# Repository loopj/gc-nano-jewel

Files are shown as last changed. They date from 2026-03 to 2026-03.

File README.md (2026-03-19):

# GC Nano LCD Jewel

Custom LCD "jewel" insert for the [GC Nano](https://bitbuilt.net/forums/threads/gc-nano-the-worlds-smallest-gamecube.5697/), using an ESP32-C3 and a lensed 0.96" round LCD.

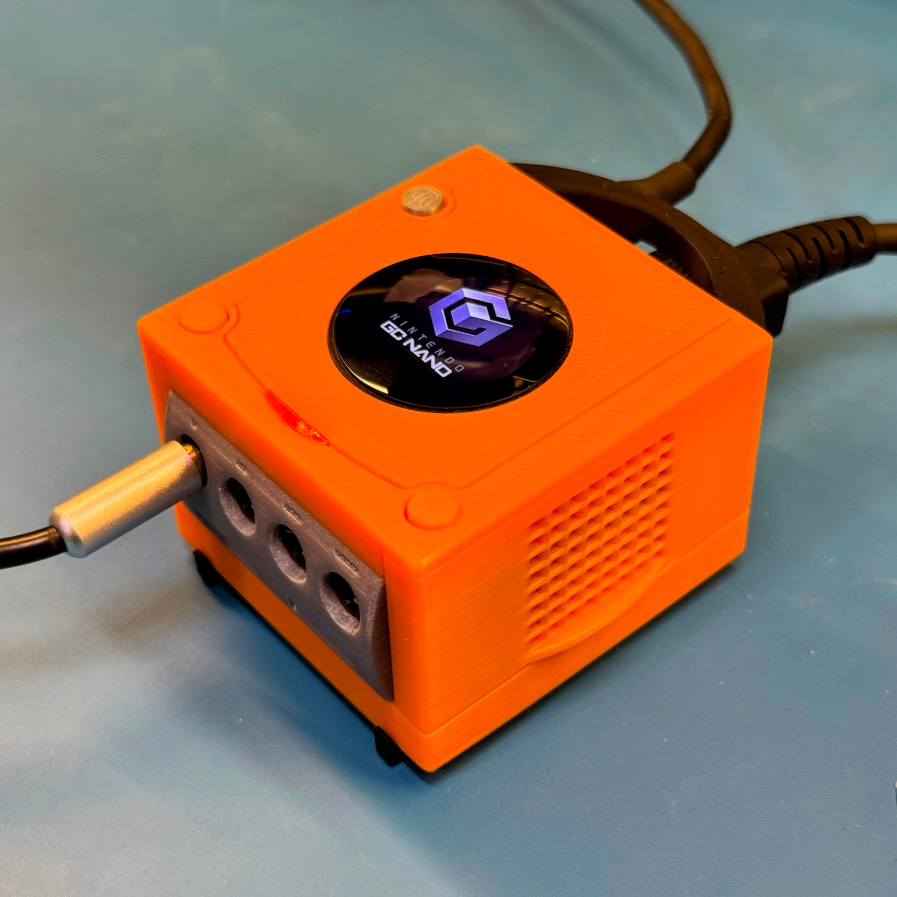
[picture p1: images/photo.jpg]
GC Nano LCD Jewel animation demo


## Features

- Fits in an unmodified GC Nano shell
- Displays a static or animated GIF (240x198, < 1,408 KB)
- WiFi access point and web interface for uploading new GIFs
- OTA firmware updates so you don't have to open the case again

## Bill of Materials

- ESP32-C3 Super Mini (or similar) - [AliExpress](https://www.aliexpress.us/item/3256808827955225.html)
- 0.96" 240x198 Round LCD - [AliExpress](https://www.aliexpress.us/item/3256806072157291.html), [docs](https://www.lcdwiki.com/0.96inch_IPS_ST7789_Module)
- Some wire
- 3D printed insert (see [`hardware/` folder](hardware/))

## Assembly

The LCD should be wired to the following pins on the ESP32-C3:

| LCD Pin | ESP32-C3 Pin | Function |
|---|---|---|
| GND | GND | Ground |
| VCC | 3.3V | Power |
| SCL | GPIO4 | SPI Clock |
| SDA | GPIO6 | SPI MOSI |
| CS | GPIO7 | SPI Chip Select  |
| DC | GPIO2 | Data/Command |
| RST | GPIO1 | Reset |

You'll also need to connect GND and 5V on the ESP32-C3 to the corresponding pads on the GC Nano top board.

The screen should press-fit from the top into the 3D printed insert, which can then be glued into the GC Nano shell. The ESP32-C3 can be mounted on the back of the insert with some double-sided tape.

Flash the firmware before closing everything up.

## Flashing the Firmware

### Using a Browser-Based Flasher

- Plug in the ESP32-C3 to your computer via USB
- Go to <https://www.espboards.dev/tools/program/> and click *Connect to ESP*
- Click *Flash firmware*
- Set the *Flash Address* to `0x0` an click *Choose File*
- Select the `factory.bin` file you downloaded from the [releases](https://github.com/loopj/gc-nano-jewel/releases) page
- Click *Program* and wait for it to finish

### Using PlatformIO

- Install PlatformIO
- Plug in the ESP32-C3 to your computer via USB
- Run `pio run -t upload` from the `firmware` directory

## Usage

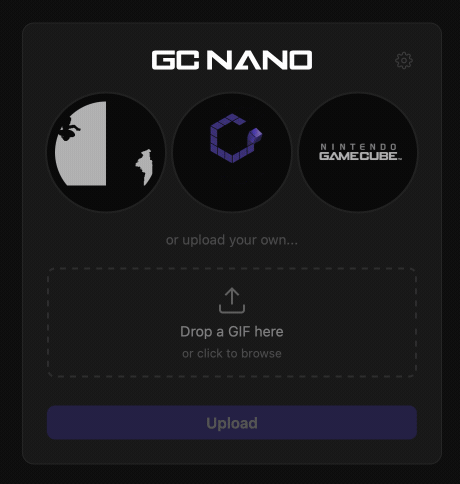
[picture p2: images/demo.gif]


### Uploading GIFs

- Connect to the "GCNANO-XXXXXX" WiFi network (password: "bitbuilt")
- Open a web browser and navigate to <http://gcnano.local>
- Upload the GIF!

### Settings

Clicking the cog icon in the top right of the page will flip to the settings page. By default, the settings page is locked. To unlock it, enter the settings password (default: "bitbuilt") and click "Unlock".

### Connecting to WiFi

By default, the firmware creates its own WiFi AP. You can instead connect to your home WiFi network by entering the SSID and password in the settings page.

### Pre-made GIFs

There are a couple of pre-made GIFs in the [`gifs/` folder](gifs/). If you want to make your own, make sure to resize it to 240x198 and keep the file size under 1,408 KB. Please send me your GIFs and I'll add them to the collection!

<table>
  <tr>
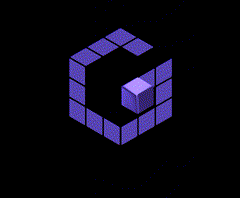
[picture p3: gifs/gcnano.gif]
    <td></td>
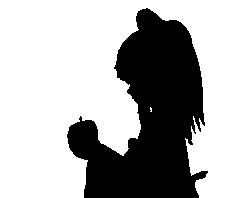
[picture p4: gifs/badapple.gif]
    <td></td>
  </tr>
</table>

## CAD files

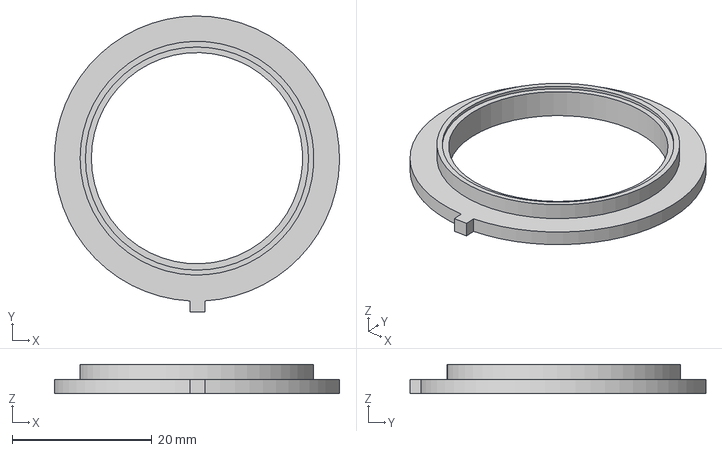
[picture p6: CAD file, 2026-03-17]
hardware/GC Nano LCD Jewel.step
40.8 x 42.3 x 4.20 mm

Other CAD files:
hardware/GC Nano LCD Jewel.stl

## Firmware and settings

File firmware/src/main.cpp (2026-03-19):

#include <AnimatedGIF.h>
#include <Arduino.h>
#include <ESPmDNS.h>
#include <LittleFS.h>
#include <Preferences.h>
#include <TFT_eSPI.h>
#include <Update.h>
#include <WebServer.h>
#include <WiFi.h>

#include "AnimatedGIF_LittleFS.h"
#include "AnimatedGIF_TFT_eSPI.h"

// Static assets
extern const uint8_t index_html_start[] asm("_binary_assets_index_html_start");
extern const uint8_t index_html_end[] asm("_binary_assets_index_html_end");
extern const uint8_t default_gif_start[] asm("_binary_assets_default_gif_start");
extern const uint8_t default_gif_end[] asm("_binary_assets_default_gif_end");

#define PASSWORD "bitbuilt"

WebServer server(80);
TFT_eSPI tft = TFT_eSPI();
AnimatedGIF gif;
bool gifPaused             = false;
bool gifNeedsReload        = false;
static bool settingsLocked = true;

void handleUnlock()
{
  Preferences prefs;
  prefs.begin("wifi", true);
  String settingsPass = prefs.getString("settingspass", "bitbuilt");
  prefs.end();
  if (server.arg("password") == settingsPass) {
    settingsLocked = false;
    server.send(200, "text/plain", "Unlocked");
  } else {
    server.send(401, "text/plain", "Incorrect password");
  }
}

void handleLock()
{
  settingsLocked = true;
  server.send(200, "text/plain", "Locked");
}

void handleGetLocked()
{
  server.send(200, "application/json", settingsLocked ? "true" : "false");
}

void handleOta()
{
  HTTPUpload &upload = server.upload();
  if (upload.status == UPLOAD_FILE_START) {
    if (settingsLocked)
      return;
    gifPaused = true;
    gif.close();
    size_t fsize = UPDATE_SIZE_UNKNOWN;
    if (server.hasArg("size"))
      fsize = server.arg("size").toInt();
    Update.begin(fsize);
  } else if (upload.status == UPLOAD_FILE_WRITE) {
    if (!settingsLocked)
      Update.write(upload.buf, upload.currentSize);
  } else if (upload.status == UPLOAD_FILE_END) {
    if (!settingsLocked)
      Update.end(true);
  }
}

void handleOtaEnd()
{
  server.sendHeader("Connection", "close");
  if (settingsLocked) {
    server.send(401, "text/plain", "Unauthorized");
    return;
  }
  if (Update.hasError()) {
    gifPaused = false;
    server.send(502, "text/plain", Update.errorString());
    return;
  }
  server.send(200, "text/plain", "Update complete, rebooting...");
  delay(500);
  ESP.restart();
}

void handleImageGet()
{
  if (!LittleFS.exists("/uploaded.gif")) {
    server.send(404, "text/plain", "No image uploaded");
    return;
  }
  File f = LittleFS.open("/uploaded.gif", "r");
  server.streamFile(f, "image/gif");
  f.close();
}

void handleImageDelete()
{
  if (!LittleFS.exists("/uploaded.gif")) {
    server.send(404, "text/plain", "No image uploaded");
    return;
  }
  gif.close();
  LittleFS.remove("/uploaded.gif");
  gifNeedsReload = true;
  server.send(200, "text/plain", "Image deleted");
}

static File uploadFile;

void handleImageUpload()
{
  HTTPUpload &upload = server.upload();

  if (upload.status == UPLOAD_FILE_START) {
    gifPaused = true;
    gif.close();
    uploadFile = LittleFS.open("/uploaded.gif", "w");
  } else if (upload.status == UPLOAD_FILE_WRITE) {
    if (uploadFile) {
      uploadFile.write(upload.buf, upload.currentSize);
    }
  } else if (upload.status == UPLOAD_FILE_END) {
    if (uploadFile) {
      uploadFile.close();
    }
  }
}

void handleImageUploadEnd()
{
  gifNeedsReload = true;
  gifPaused      = false;
  server.sendHeader("Connection", "close");
  server.send(200, "text/plain", "Image uploaded successfully");
}

void handleGetSettings()
{
  if (settingsLocked) {
    server.send(401, "text/plain", "Unauthorized");
    return;
  }

  Preferences prefs;
  prefs.begin("wifi", true);
  String savedSsid = prefs.getString("ssid", "");
  bool hasPassword = prefs.getString("pass", "").length() > 0;
  prefs.end();

  bool isSta     = WiFi.getMode() == WIFI_STA;
  bool connected = isSta && WiFi.status() == WL_CONNECTED;
  String ip      = connected ? WiFi.localIP().toString() : WiFi.softAPIP().toString();

  String json = "{";
  json += "\"ssid\":\"" + savedSsid + "\",";
  json += "\"hasPassword\":" + String(hasPassword ? "true" : "false") + ",";
  json += "\"mode\":\"" + String(isSta ? "sta" : "ap") + "\",";
  json += "\"connected\":" + String(connected ? "true" : "false") + ",";
  json += "\"ip\":\"" + ip + "\"";
  json += "}";
  server.send(200, "application/json", json);
}

void handleSaveSettings()
{
  if (settingsLocked) {
    server.send(401, "text/plain", "Unauthorized");
    return;
  }

  String newSsid         = server.arg("ssid");
  String newPass         = server.arg("pass");
  String newSettingsPass = server.arg("settingspass");

  Preferences prefs;
  prefs.begin("wifi", false);
  prefs.putString("ssid", newSsid);
  if (newPass.length() > 0)
    prefs.putString("pass", newPass);
  if (newSettingsPass.length() > 0)
    prefs.putString("settingspass", newSettingsPass);
  prefs.end();

  server.send(200, "text/plain", "Saved. Rebooting...");
  delay(500);
  ESP.restart();
}

void setup()
{
  // Initialize filesystem
  LittleFS.begin(true);

  // Initialize screen
  tft.init();
  tft.fillScreen(TFT_BLACK);

  // Initialize GIF decoder
  gif.begin(BIG_ENDIAN_PIXELS);

  // Generate a unique SSID based on MAC address (used as AP fallback)
  char apSsid[14];
  long unsigned int espmac = ESP.getEfuseMac() >> 24;
  snprintf(apSsid, sizeof(apSsid), "GCNANO-%06lX", espmac);

  // Try to connect to a saved WiFi network, otherwise start AP
  Preferences prefs;
  prefs.begin("wifi", true);
  String savedSsid = prefs.getString("ssid", "");
  String savedPass = prefs.getString("pass", "");
  prefs.end();

  if (savedSsid.length() > 0) {
    WiFi.mode(WIFI_STA);
    WiFi.begin(savedSsid.c_str(), savedPass.c_str());
    unsigned long start = millis();
    while (WiFi.status() != WL_CONNECTED && millis() - start < 10000) {
      delay(200);
    }
  }

  if (WiFi.status() != WL_CONNECTED) {
    WiFi.mode(WIFI_AP);
    WiFi.softAP(apSsid, PASSWORD);
  }

  // Start mDNS responder for "gcnano.local"
  MDNS.begin("gcnano");

  // Initialize web server
  server.on("/", HTTP_GET, []() {
    server.send_P(200, "text/html", (const char *)index_html_start, index_html_end - index_html_start);
  });
  server.on("/ota", HTTP_POST, handleOtaEnd, handleOta);
  server.on("/image", HTTP_GET, handleImageGet);
  server.on("/image", HTTP_POST, handleImageUploadEnd, handleImageUpload);
  server.on("/image", HTTP_DELETE, handleImageDelete);
  server.on("/settings", HTTP_GET, handleGetSettings);
  server.on("/settings", HTTP_POST, handleSaveSettings);
  server.on("/lock", HTTP_GET, handleGetLocked);
  server.on("/lock", HTTP_PUT, handleLock);
  server.on("/lock", HTTP_DELETE, handleUnlock);
  server.begin();
}

void playGif()
{
  // Open GIF, falling back to default if uploaded one fails
  if (!gif.open("/uploaded.gif", GIFOpenFile, GIFCloseFile, GIFReadFile, GIFSeekFile, GIFDraw))
    if (!gif.openFLASH((uint8_t *)default_gif_start, default_gif_end - default_gif_start, GIFDraw))
      return;

  gifNeedsReload = false;

  // Start SPI transaction to screen
  tft.startWrite();

  // Play each GIF frame, checking for web server requests between frames
  while (!gifPaused && !gifNeedsReload && gif.playFrame(true, NULL)) {
    server.handleClient();
  }

  // End SPI transaction and close GIF
  tft.endWrite();
  gif.close();
}

void loop()
{
  // Handle web server requests
  server.handleClient();

  // Play GIF if not paused
  if (!gifPaused)
    playGif();
}

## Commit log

2026-03-17 Initial release
    [GC Nano LCD Jewel.step, GC Nano LCD Jewel.stl, partitions.csv]
2026-03-17 Add assembly/pinout info
2026-03-17 Use default esp32/arduino partition size
    [partitions.csv]
